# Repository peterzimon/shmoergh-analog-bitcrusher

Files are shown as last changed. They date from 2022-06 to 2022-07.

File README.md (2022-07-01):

# Shmøergh Analog Bitcrusher

Analog bitcrusher with variable downsampling between about 100Hz and ~20kHz rate 
and wet/dry control. Note that this is a fully analog unit, no coding involved. 
KiCad version: 5.x but theoretically should work on 6.x.

Simulations are made with [CircuitJS](https://www.falstad.com/circuit/circuitjs.html) 

Find a bit more detailed circuit description on the schematics and in this 
[blogpost](https://www.peterzimon.com/analog-bitcruser).

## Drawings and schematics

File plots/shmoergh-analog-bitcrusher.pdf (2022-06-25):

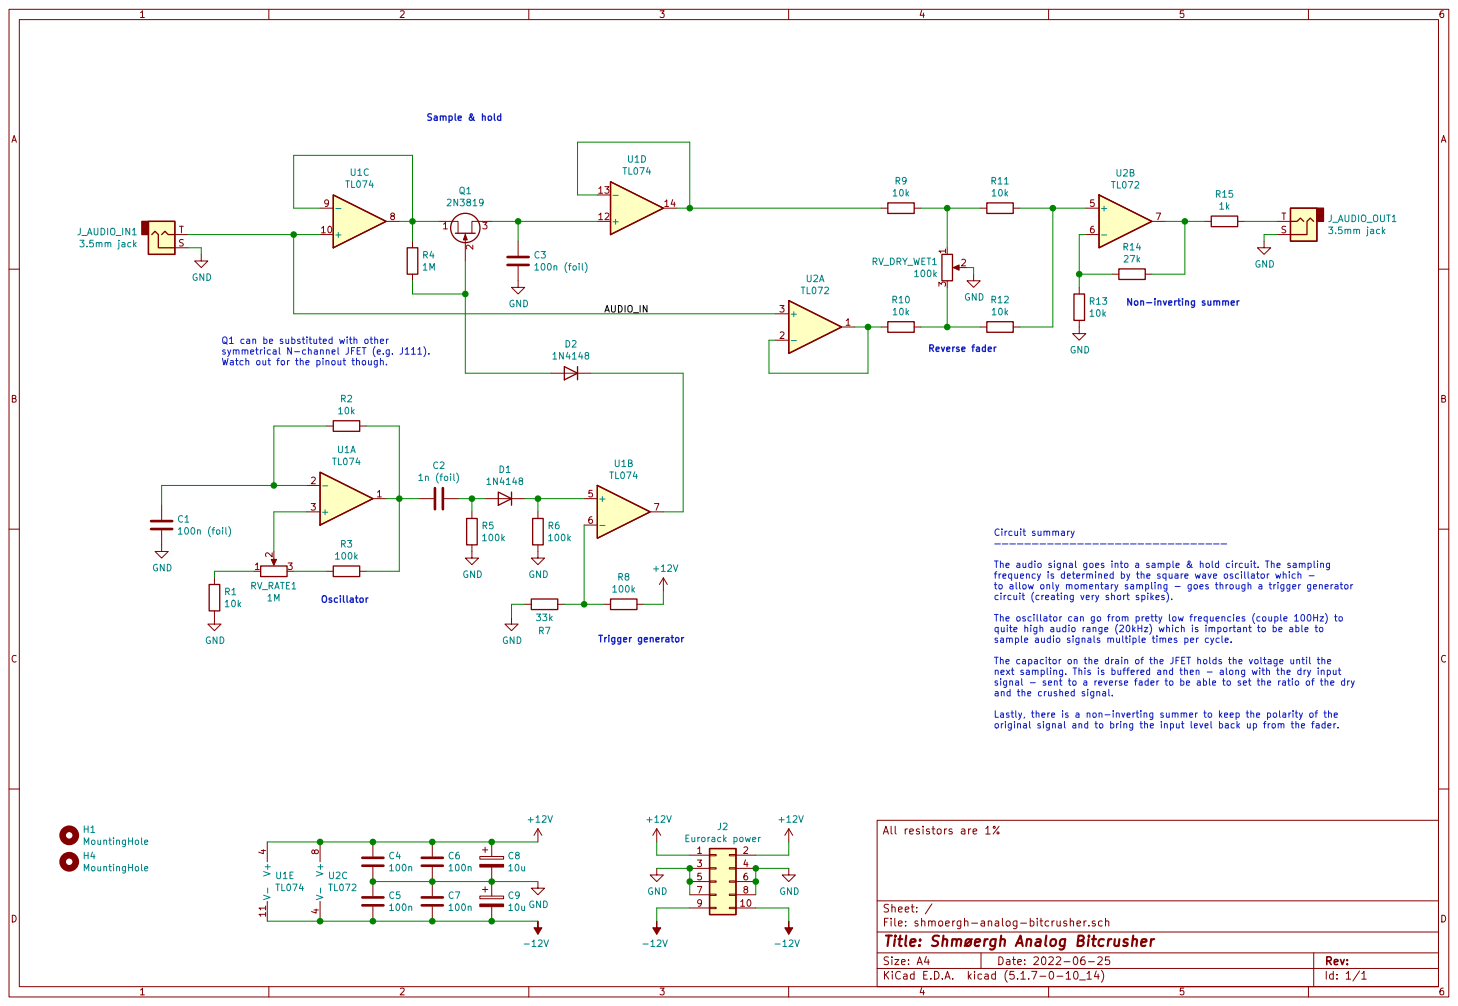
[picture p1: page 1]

original signal and to bring the input level back up from the fader. Reverse fader Sample & hold

Non-inverting summer Q1 can be substituted with other symmetrical N-channel JFET (e.g. J111).

Watch out for the pinout though.

The audio signal goes into a sample & hold circuit. The sampling
frequency is determined by the square wave oscillator which -
to allow only momentary sampling - goes through a trigger generator
circuit (creating very short spikes).

The oscillator can go from pretty low frequencies (couple 100Hz) to
quite high audio range (20kHz) which is important to be able to
sample audio signals multiple times per cycle.

The capacitor on the drain of the JFET holds the voltage until the
next sampling. This is buffered and then - along with the dry input
signal - sent to a reverse fader to be able to set the ratio of the dry
and the crushed signal.

Lastly, there is a non-inverting summer to keep the polarity of the

File: shmoergh-analog-bitcrusher.sch Sheet: / All resistors are 1%

Id: 1/1 Title: Shmøergh Analog Bitcrusher

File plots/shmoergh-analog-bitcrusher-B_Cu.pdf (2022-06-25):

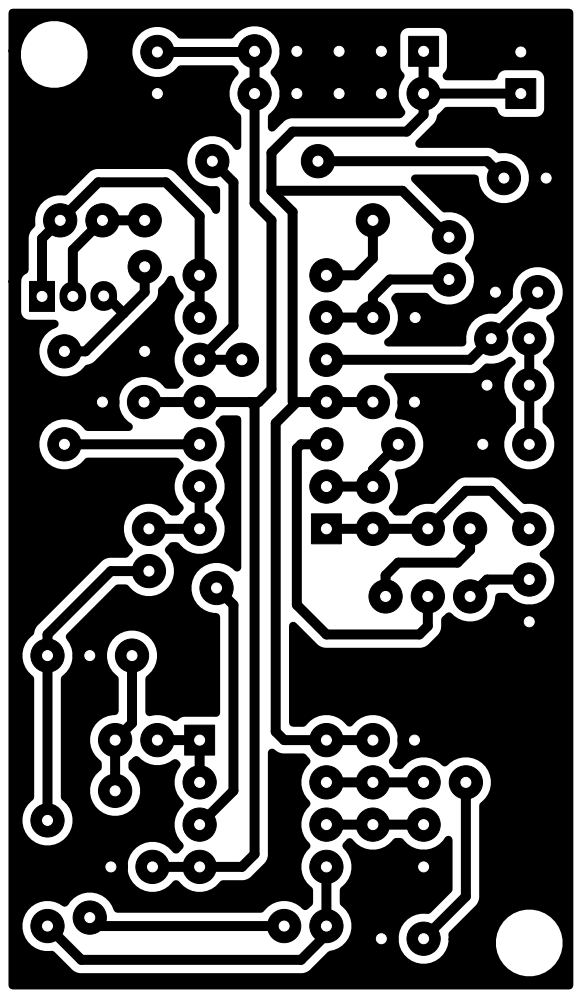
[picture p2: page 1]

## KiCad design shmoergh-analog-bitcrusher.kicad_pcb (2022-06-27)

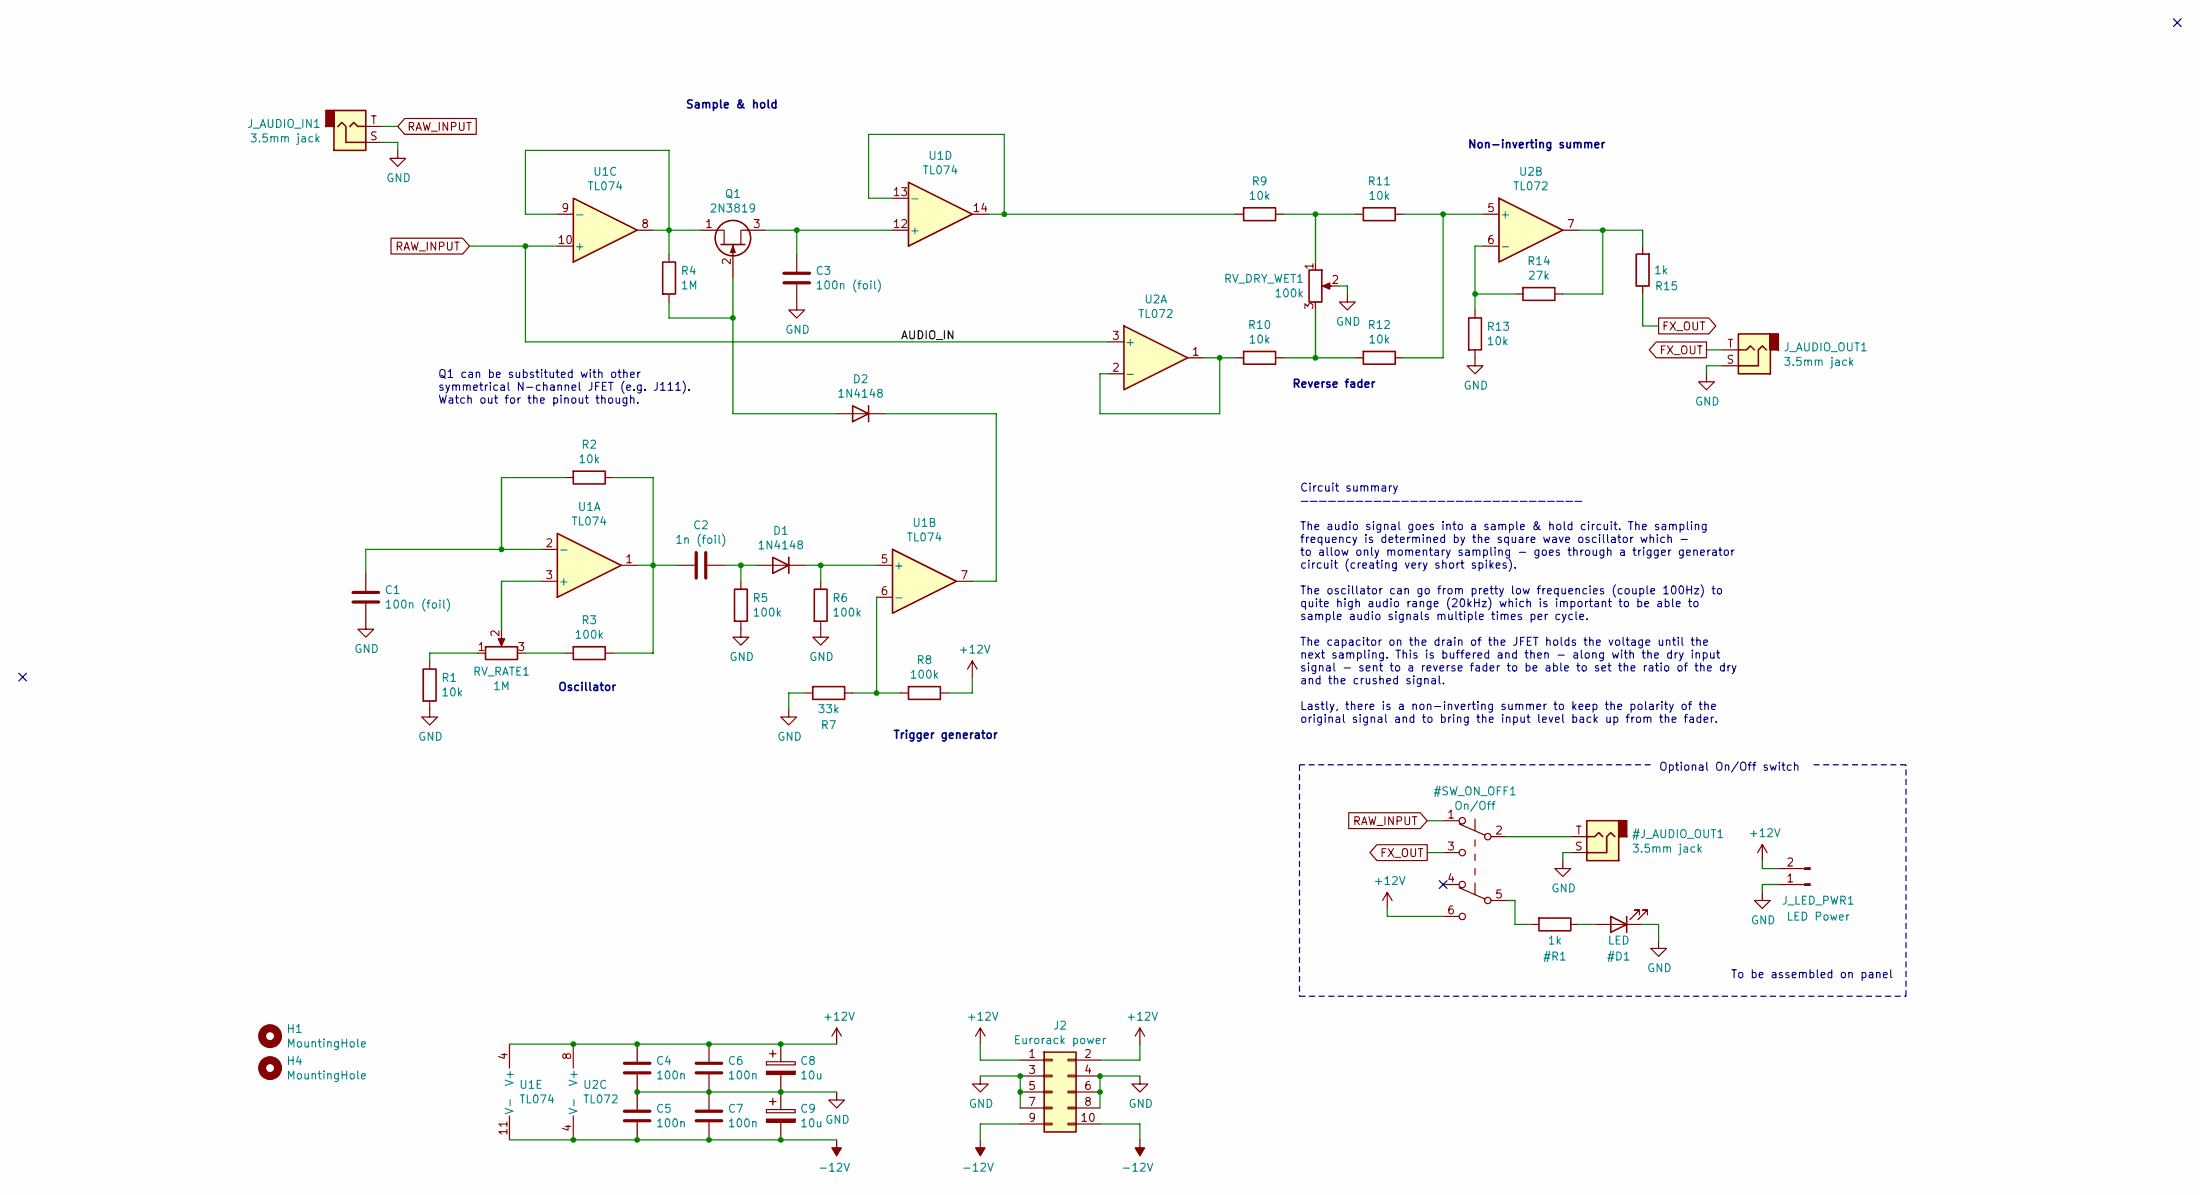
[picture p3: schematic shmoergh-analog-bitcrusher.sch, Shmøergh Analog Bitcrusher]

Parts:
C1, C3: 100n (foil); C_Foil_P5.48mm
C2: 1n (foil); C_Foil_P5.48mm
C4, C5, C6, C7: 100n; C_Disc_D5.0mm_W2.5mm_P2.50mm
C8, C9: 10u; CP_Radial_D5.0mm_P2.50mm
D1, D2: 1N4148; D_Axial-Vertical
H1, H4: MountingHole; MountingHole_3mm
J2: Eurorack power; Eurorack_Power_Supply
J_AUDIO_IN1: 3.5mm jack; NSL25_01x02_Vertical-AudioJack-TS
J_AUDIO_OUT1: 3.5mm jack; NSL25_01x02_Vertical-AudioJack-TS
J_LED_PWR1: LED Power; NSL25_01x02_Vertical
Q1: 2N3819; TO-92_Inline
R1, R2, R9, R10, R11, R12, R13: 10k; R_Axial_Vertical
R3, R5, R6, R8: 100k; R_Axial_Vertical
R4: 1M; R_Axial_Vertical
R7: 33k; R_Axial_Vertical
R14: 27k; R_Axial_Vertical
R15: 1k; R_Axial_Vertical
RV_DRY_WET1: 100k; NSL25_01x03_Vertical
RV_RATE1: 1M; NSL25_01x03_Vertical
U1: TL074; DIP-14_W7.62mm
U2: TL072; DIP-8_W7.62mm

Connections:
-12V: C5.2, C7.2, C9.2, J2.9, J2.10, U1.11 (V-), U2.4 (V-)
unnamed: C1.1, R2.2, U1.2 (-)
unnamed: C2.1, D1.2 (A), R5.1
unnamed: C2.2, R2.1, R3.1, U1.1
unnamed: C3.1, Q1.3 (S), U1.12 (+)
unnamed: D1.1 (K), R6.1, U1.5 (+)
unnamed: D2.1 (K), U1.7
unnamed: D2.2 (A), Q1.2 (G), R4.2
unnamed: Q1.1 (D), R4.1, U1.8, U1.9 (-)
unnamed: R1.1, RV_RATE1.1
unnamed: R3.2, RV_RATE1.3
unnamed: R7.1, R8.2, U1.6 (-)
unnamed: R9.2, U1.13 (-), U1.14
unnamed: R10.1, R12.2, RV_DRY_WET1.3
unnamed: R10.2, U2.1, U2.2 (-)
unnamed: R11.1, R12.1, U2.5 (+)
unnamed: R9.1, R11.2, RV_DRY_WET1.1
unnamed: R13.1, R14.2, U2.6 (-)
unnamed: R14.1, R15.2, U2.7
unnamed: RV_RATE1.2, U1.3 (+)

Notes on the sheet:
Oscillator
Trigger generator
Reverse fader
Sample & hold
Non-inverting summer
Q1 can be substituted with other symmetrical N-channel JFET (e.g. J111). Watch out for the pinout though.
Circuit summary ——————————————————————————————— The audio signal goes into a sample & hold circuit. The sampling frequency is determined by the square wave oscillator which - to allow only momentary sampling - goes through a trigger generator circuit (creating very short spikes). The oscillator can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
Optional On/Off switch
To be assembled on panel

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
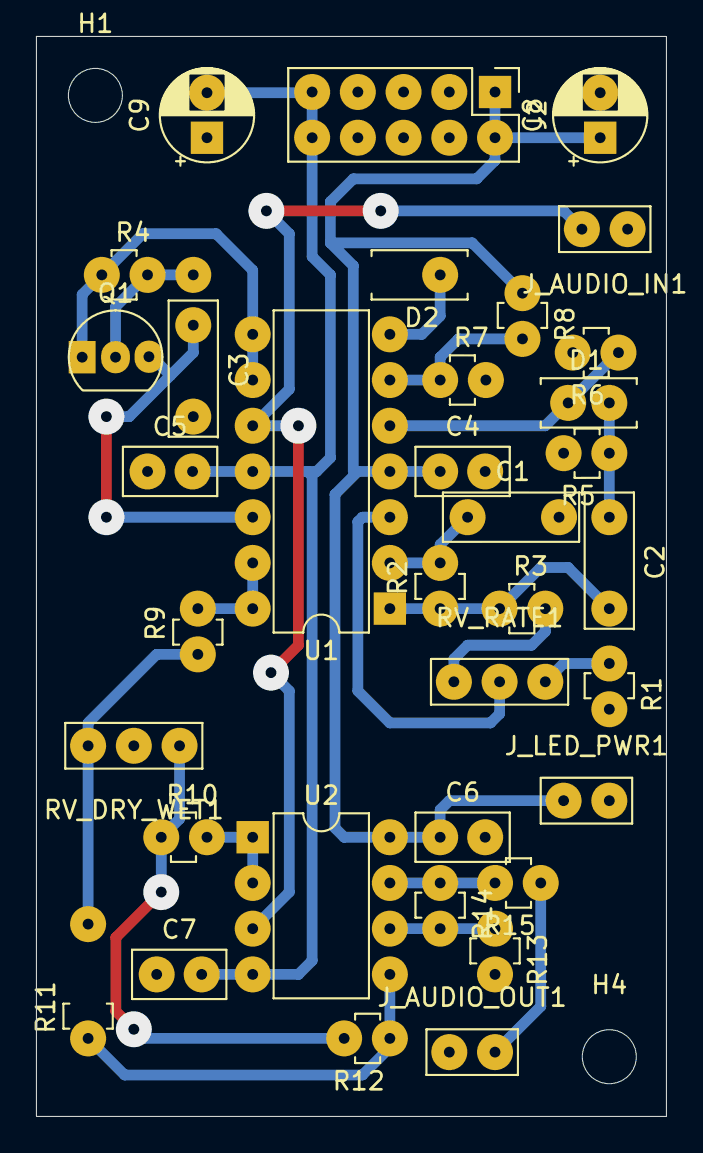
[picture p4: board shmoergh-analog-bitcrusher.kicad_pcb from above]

Board: 2 copper layers, 35.0 x 60.0 mm, 37 parts (0 on the bottom side), 24 nets.

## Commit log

2022-06-25 Added bitcrusher circuit
    [shmoergh-analog-bitcrusher.kicad_pcb, shmoergh-analog-bitcrusher.sch]
2022-06-25 Updated plots
    [shmoergh-analog-bitcrusher.kicad_pcb]
2022-06-27 Added on/off switch to schematics
    [shmoergh-analog-bitcrusher.kicad_pcb, shmoergh-analog-bitcrusher.sch]
